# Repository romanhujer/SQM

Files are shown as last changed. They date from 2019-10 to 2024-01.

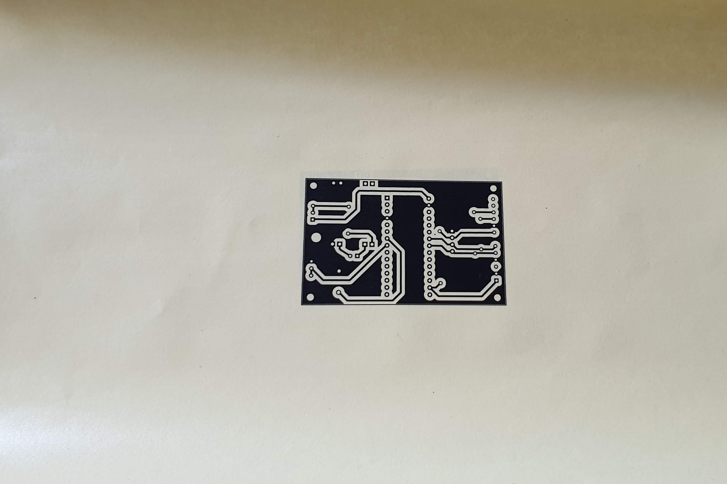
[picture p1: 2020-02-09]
Doc/PCB-Laser-print.jpg

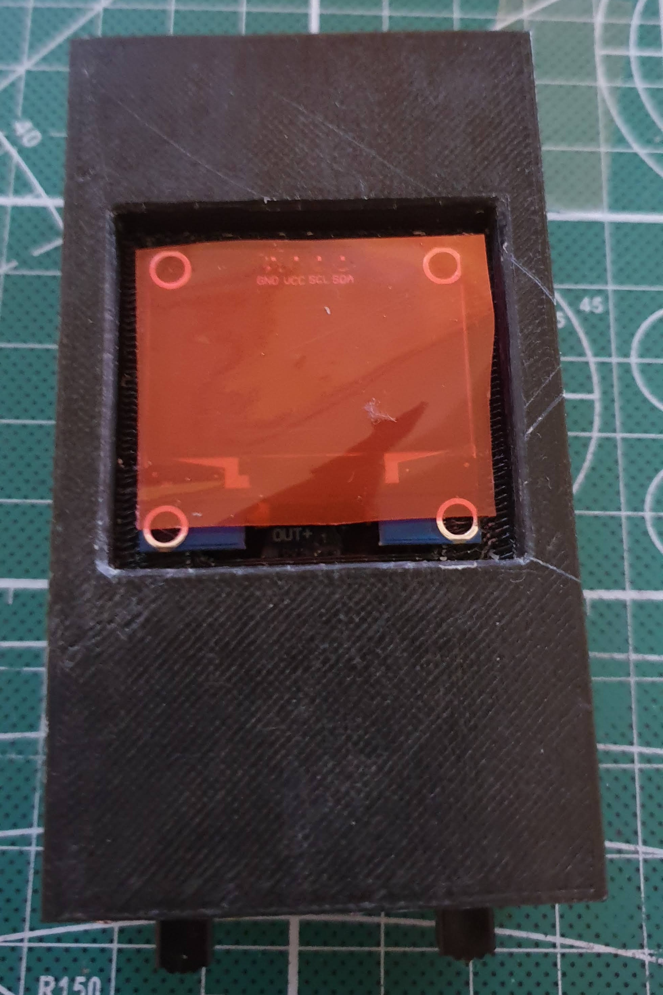
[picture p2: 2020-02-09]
Doc/install display.jpg

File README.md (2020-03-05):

# SQM
Arduino compatible Sky Quality Meter using the TSL2591
   
  base on https://github.com/gshau/SQM_TSL2591/
 
  and BME280 weather sensor 

## [Handheld version on base Adruino NANO](https://github.com/romanhujer/SQM/tree/master/SQM_nano)
  
  Used  128x64 OLED display 0.96" (SSD1306) or 1.3" (SH1106)
  and USB Control mode use derived Unihedron serial protokol

  * Wiring diagram a PCB  on [EasyEDA](https://easyeda.com/hujer.roman/sqm-hr)
  * Final 3Dmodel for case is on [Thingiverse](https://www.thingiverse.com/thing:4051029)

## [Fix instalaltion Vesion on base ESP8266 (ESP-01 or ESP-12)](https://github.com/romanhujer/SQM/tree/master/SQM_esp)

  Used wifi to send measurement data to server 
  * Wiring diagram a PCB for ESP-01 on  [EasyEDA](https://easyeda.com/hujer.roman/esp-01-sqm)
    * Basic simple version
  
  * Wiring diagram a PCB for ESP-12 on [EasyEDA](https://easyeda.com/hujer.roman/sqm-esp-v2) 
    * Possible battery operation and deepsleep  mode

## [Handheld Pro version on base ESP8266 (ESP-12)](https://github.com/romanhujer/SQM/tree/master/SQM_pro)

  Wiring diagram a PCB on [EasyEDA](https://easyeda.com/hujer.roman/sqm-esp-v2_copy) 
  
  * NOTE: The wiring diagram may change !
  
  Featuers plan:
   * 128x64 OLED display  1.3" (SH1106)
   * GPS  mudule (Optional)
   * For send measurement data to server used Wifi or Unihedron serial protokol

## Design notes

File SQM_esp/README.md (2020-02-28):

# ESP SQM
This is the EPS-01 and ESP8266 SQM 

# Installing the ESP8266 Platform
Before you can flash the firmware on your ESP8266 device, you need to install the ESP8266
platform for the Arduino IDE.

Under Preferences add this line in the additional "Boards Manager" area:
  http://arduino.esp8266.com/stable/package_esp8266com_index.json

Then from the "Tools, Boards, Boards Manager" menu select and install the ESP8266 add-on.

# Required libraries
* Adafruit Unified Sensor
* BMx280MI

# Flashing 
The exact flashing procedure depends on which ESP8826 device you will be using.

In the Arduino IDE, pick your device from "Tools, Boards". 

For an ESP-01, select "Generic 8266 Module".

Pin CHPD/EN must be HIGH (connected to 3.3V)
Pin GPIO0 must be LOW (connected to GND).  Use flash swich on PCB and reset

For the ESP-01, use the following parameters under Tools:

- Board: "Generic ESP8266 Module"
- Flash Mode: "DIO"
- Erase Flash: "Sketch + WiFi Settings"
- Flash Size: "1M (64K SPIFFS)" (Most ESP01 have 1M, older ones have 512K)
- Flash Frequency: "40MHz"
- CPU Frequency: "80 MHz"
- Reset Method: "ck"
- Upload Speed: "115200"
- Debug Port: "Disabled"
- Debug Level: "None"

Open the SQM_esp.ino file inside this folder. Check the "Config.h" file and set your vaules  for 
<pre>
 const char* sensor_key = "xxxxxxxxxxxxxxxxxx";  // For auth on web server
 const char* host = "my.cloud.iot";
 String app      = "/app.bin";  //URI for HTTP GET  app
 const char* ssid  = "my_ssid";
 const char* password = "my_password";
 
</pre>

# Wiring and PCB 
see
* https://easyeda.com/hujer.roman/esp-01-sqm
* https://easyeda.com/hujer.roman/sqm-esp-v2

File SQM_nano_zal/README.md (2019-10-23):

# SQM
Arduino compatible Sky Quality Meter using the TSL2591
   
  base in https://github.com/gshau/SQM_TSL2591/
 
  and BME280 weather sensor 
  
  and 128x64 OLED display 0.96" (SSD1306) or 1.3" (SH1106)

  Wiring diagram a PCB  on   https://easyeda.com/hujer.roman/sqm-hr

## Features

### USB Control mode use derived Unihedron serial protokol

#### Box info (Original Unihedron protokol)
* Request: ix 
* Response:  i,00000002,00000003,00000001,20191012

#### Read data  (Original Unihedron protokol)
* Request: rx  
* Response: r, 10.28m,0000000000Hz,0000000002c,000005.000s, 026.2C
or
* Request: ux  
* Response: u, 10.33m,0000000000Hz,0000000004c,000005.000s, 026.4C

#### Read extension data with weather informations (is my extension)
* Request: wx  
* Response: w, 11.87m,0.04e,00121i,00834v,0000000002c,A5,11,040h,0952p, 026.1C
 
#### Read config data  
* Request:  gx
* Response: g, 000.00m, 000.0C,TC:Y,A5,11,DC:0
 
#### Write SQM offset to EEPROM value range (-25m ... 25m)
Negative value: 
* Request:  zcal1-0.05x
* Response: z,1,-00.05m

Positive value:  
* Request:  zcal100.01x
* Response: z,1, 00.01m 

#### Write Temperature offset to EEPROM value range (-50°C ... 50°C)
Negative value: 
* Request:  zcal2-1.5x
* Response: z,2,-01.5C 

Positive value:  
* Request:  zcal2 00.5x
* Response: z,2, 00.5C 

#### Write default display contras to EEPROM value range (0-255) 
* Request:  zcal3 005x
* Response: z,3,005

#### Enabel SQM  temperature calibration 

* Request: zcalex
* Response: zxeaL 

#### Disable SQM  temperature calibration   (note lower case "d")

* Request:  zcaldx
* Response: zxdaL 

#### Erase EEPROM set to default value 

* Request: zcalDx
* Response: zxdL 

#### Oled display mode

* Request: A50x   Disable OLED display in USB mode
* Request: A51x   Enable OLED display in USB mode
* Request: A5dx   Disable auto dimmer (contras) for OLED display
* Request: A5ex   Enable auto dimmer (contras) for OLED display
* Request: A5x    Query for current OLED display mode

* Response: A5,xy 

  x... 0 - disable 1 - enable OLED Display in USB mode 
  
  y... 0 - disable 1 - enable auto Dimmer (contras) for OLED Display

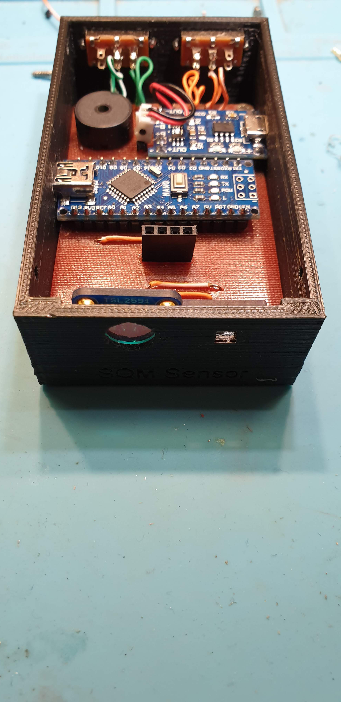
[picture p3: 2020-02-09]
Doc/in box1.jpg

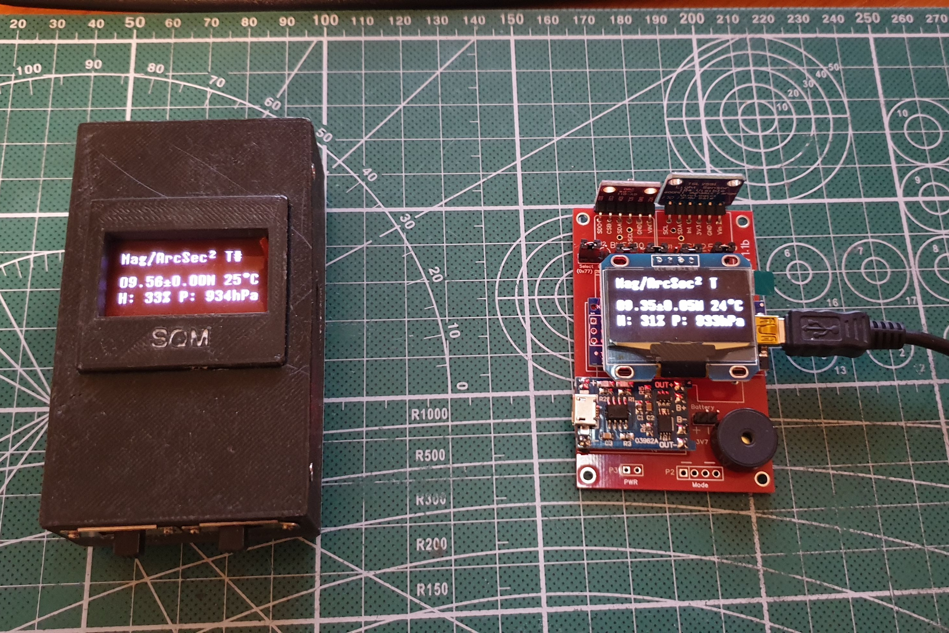
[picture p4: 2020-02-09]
Doc/Prototype II.jpg

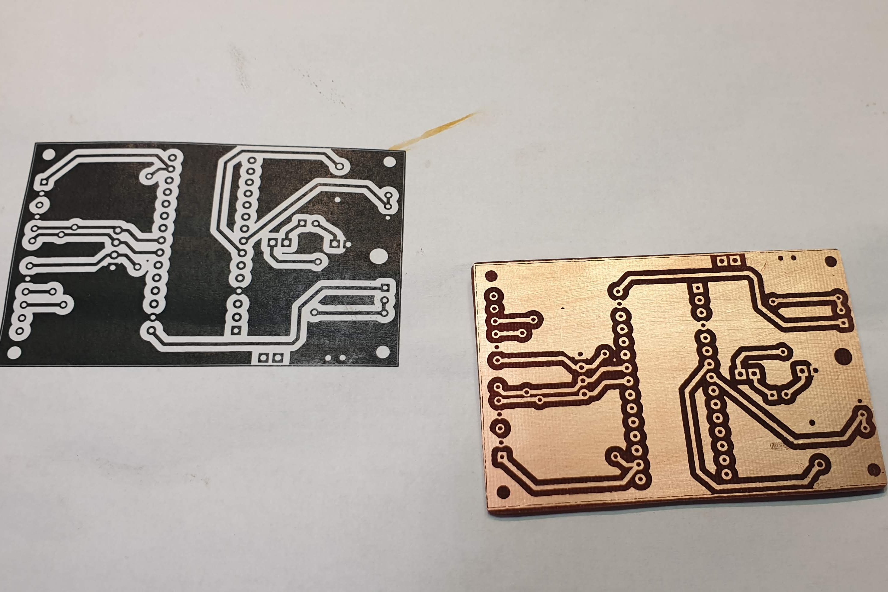
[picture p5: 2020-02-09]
Doc/HomeMadePCB-V1.0.jpg

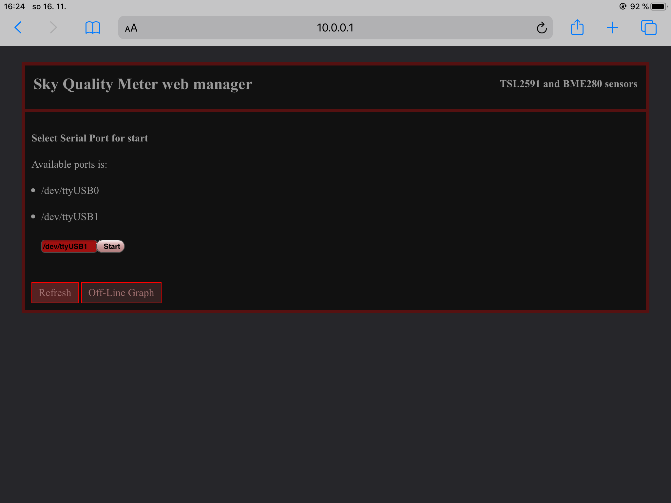
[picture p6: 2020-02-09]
Doc/WebManager Init.PNG

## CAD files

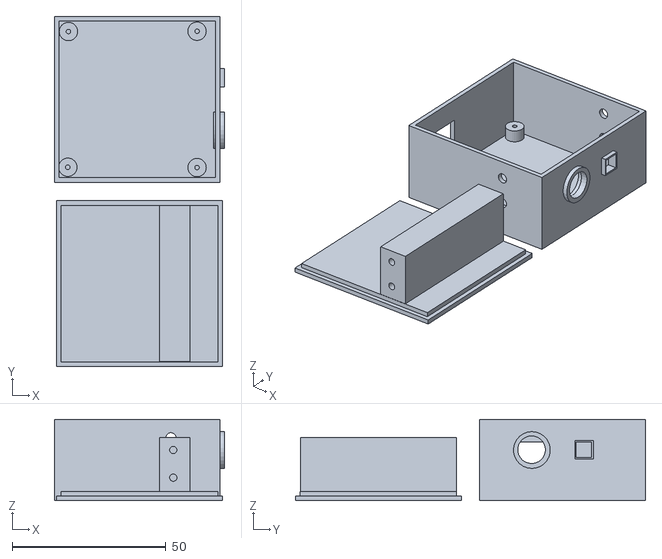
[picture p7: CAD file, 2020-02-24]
3DModelsForCase/stl_esp01/ESP-01-SQM1-main.stl
55.5 x 114.0 x 26.5

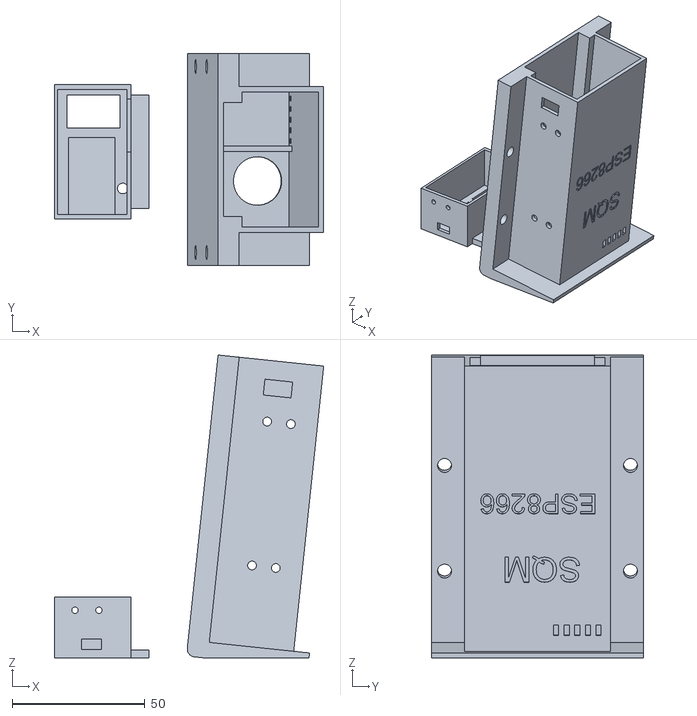
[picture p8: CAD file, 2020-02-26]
3DModelsForCase/stl_esp8266/SQM-ESP8266-cover-main.stl
101.5 x 80.0 x 114.1

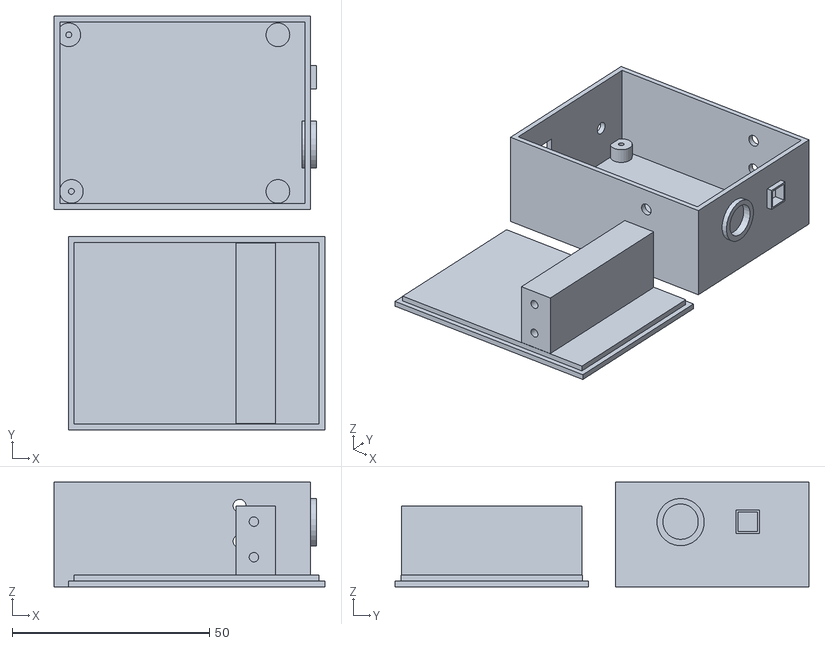
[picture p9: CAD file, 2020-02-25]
3DModelsForCase/stl_esp8266/SQM-ESP8266-box_main.stl
68.6 x 104.8 x 26.5

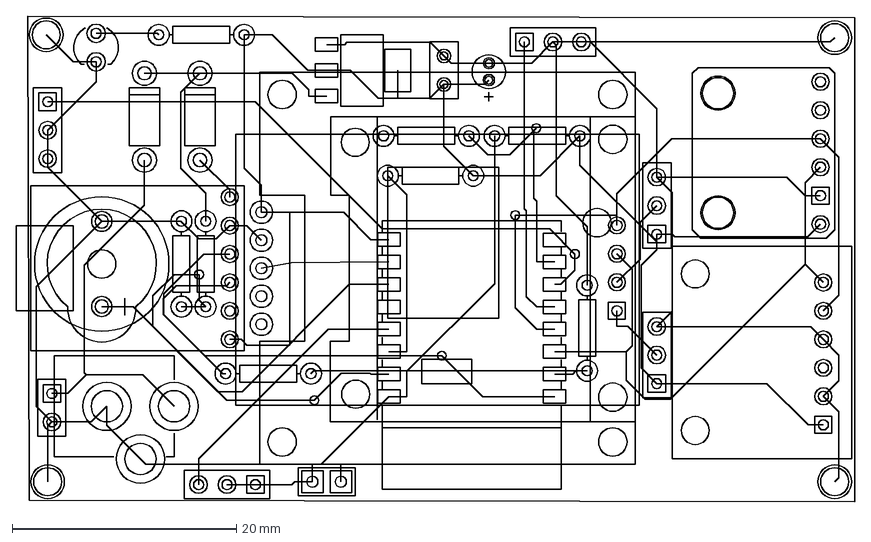
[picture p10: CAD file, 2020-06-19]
3DModelsForCase/SQM ESP pro V2.5_2020-06-01_20-28-58.dxf
74.8 x 43.3 mm

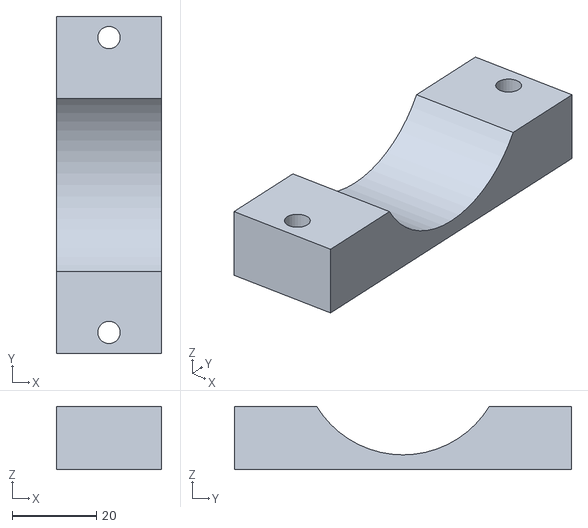
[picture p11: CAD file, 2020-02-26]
3DModelsForCase/stl_esp01/SQM-ESP-holder.stl
25.0 x 80.0 x 15.0

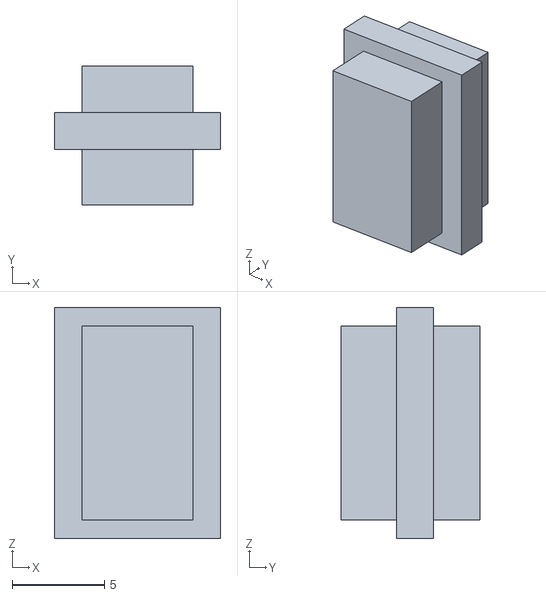
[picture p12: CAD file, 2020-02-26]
3DModelsForCase/stl_esp8266/SQM-ESP8266-usb_fixed.obj
9.00 x 7.50 x 12.5

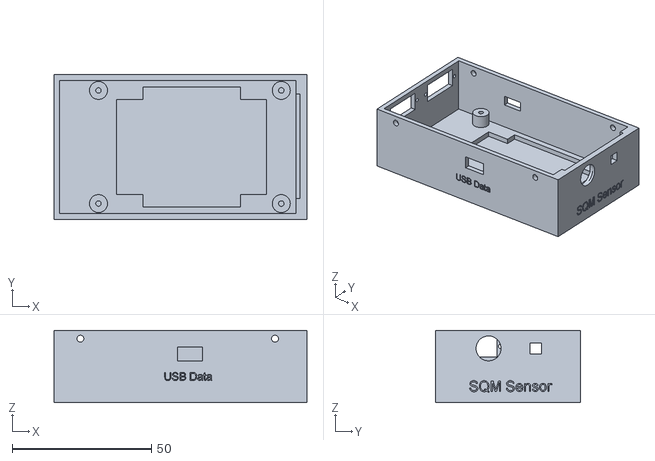
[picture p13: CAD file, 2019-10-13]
3DModelsForCase/stl_nano/SQMBoxB_fixed.stl
91.0 x 52.0 x 26.0

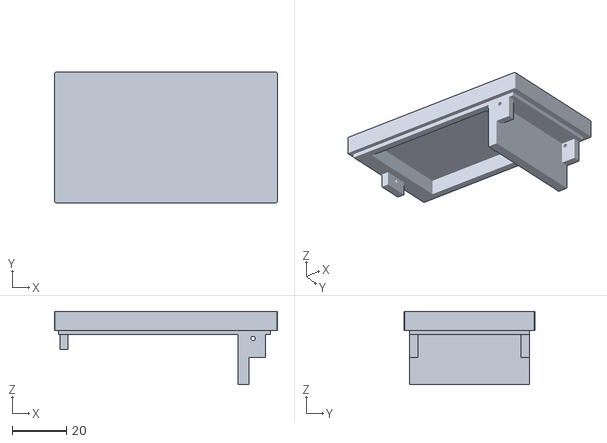
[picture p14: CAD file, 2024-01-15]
3DModelsForCase/stl_pro/SQM_BOX-Fillet002.stl
82.0 x 48.0 x 27.0

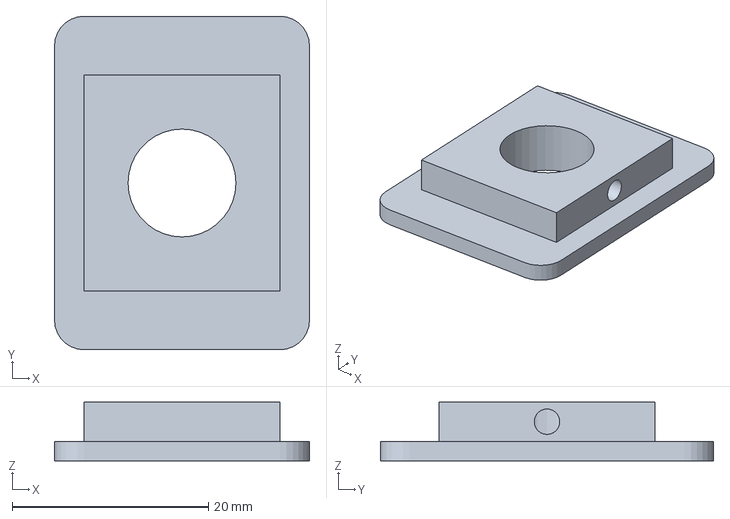
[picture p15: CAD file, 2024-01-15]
SQM_pro/master.3mf
26.0 x 34.0 x 6.00 mm

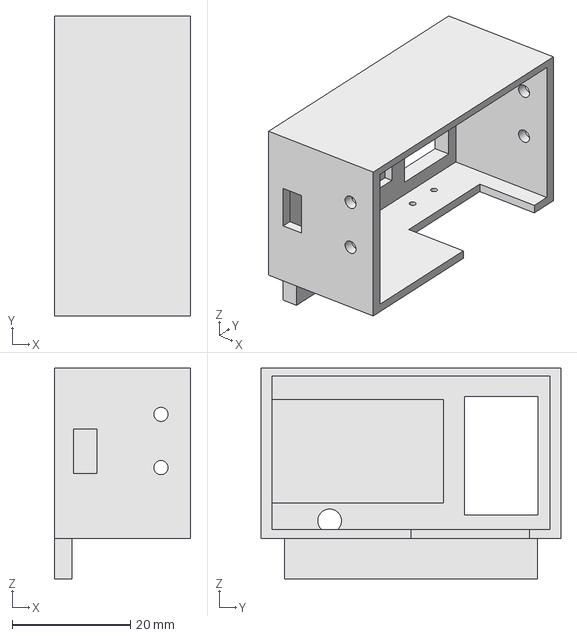
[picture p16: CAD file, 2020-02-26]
3DModelsForCase/SQM_BOX.FCStd
23.0 x 50.7 x 35.6 mm

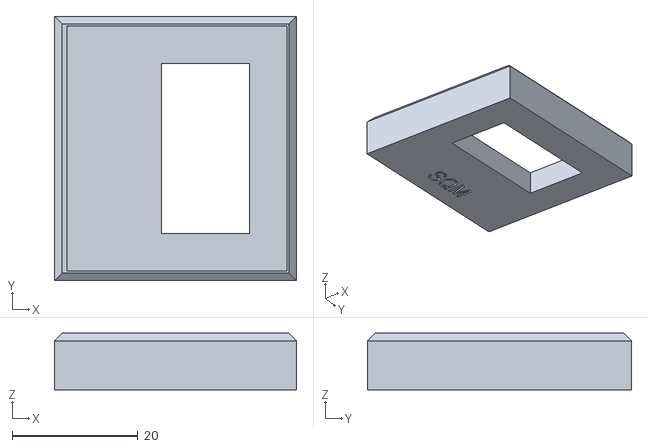
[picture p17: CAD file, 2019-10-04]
3DModelsForCase/stl_nano/SQMFaceSSD1306_fixed.stl
38.5 x 42.0 x 9.00

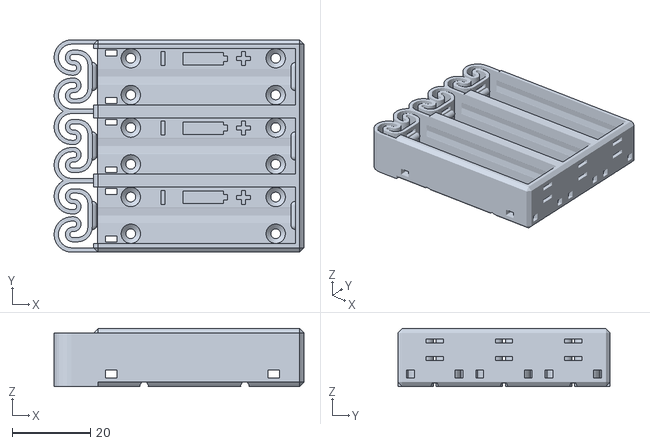
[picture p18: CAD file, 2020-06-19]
3DModelsForCase/stl_pro/flexbatterAAx3.stl
64.0 x 54.4 x 14.9

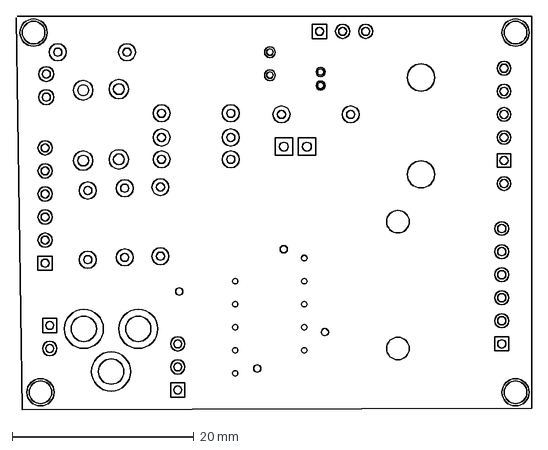
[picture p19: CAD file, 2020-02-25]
3DModelsForCase/SQM ESP v2.dxf
56.8 x 43.3 mm

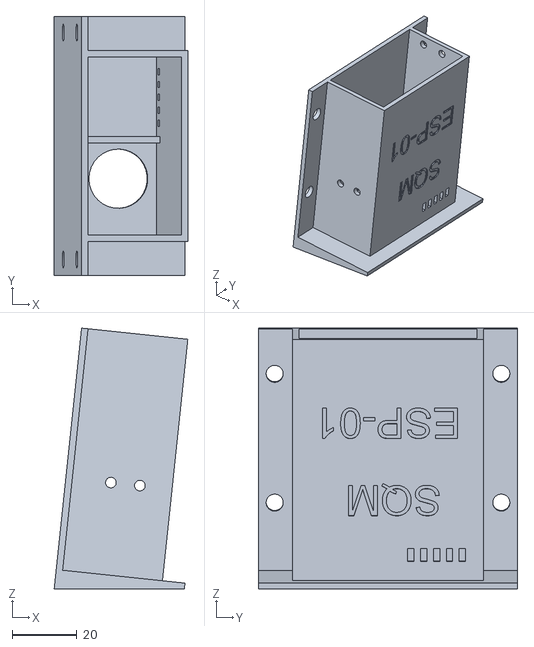
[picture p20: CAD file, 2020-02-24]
3DModelsForCase/stl_esp01/ESP-01-SQM-cover.stl
41.3 x 80.0 x 80.6

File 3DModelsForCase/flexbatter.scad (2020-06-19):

//////////////////////////////////////////////////////////////////////////////////////
///
///  FLEXBATTER: Flexing battery holder with built-in spring
///
///  This file generates battery holders for arbitrary cylindrical sizes.
///  The number of batteries and their size is fully parametrized.
///
///  The usual metallic spring at the minus pole is replaced by a
///  flexible printed spring, which is pressing the contacts firmly to 
///  the battery.
///
///  The contacts for the plus and minus pole can easily be made by
///  a few windings of the uninsulated ends of the connecting wires.
///  Each battery compartment contains are several holes to the outside
///  as well ad to the neighboring compartments, through which connecting
///  wires can be passed for easy configuring of parallel, serial or
///  balanced-serial battery packs.
///  
///  The preconfigured battery sizes are:
///  AA, AAA, C, D, 18650(Li-Ion), 18650P(protected Li-Ion), CR123A(16340)
///  
///  Given that the printed plastic spring needs to be flexible, ABS is the material
///  of choice here.
///
//////////////////////////////////////////////////////////////////////////////////////
///
///  2014-09-09 Heinz Spiess, Switzerland
///
///  released under Creative Commons - Attribution - Share Alike licence (CC BY-SA)
//////////////////////////////////////////////////////////////////////////////////////

flexbatterAAA(n=2);

// build a cube with chamfered edges
module chamfered_cube(size,d=1){
   hull(){
     translate([d,d,0])cube(size-2*[d,d,0]);
     translate([0,d,d])cube(size-2*[0,d,d]);
     translate([d,0,d])cube(size-2*[d,0,d]);
   }
}


// draw an arc width height h between radius r1..r2 and angles a1..a2
module arc(r1,r2,h,a1=0,a2=0){
     if(a2-a1<=180){
        difference(){
           cylinder(r=r2,h=h);
           translate([0,0,-1])cylinder(r=r1,h=h+2);
	   rotate(a2)translate([-r1-r2,0,-1])cube([2*(r1+r2),2*(r1+r2),h+2]);
	   rotate(a1+180)translate([-r1-r2,0,-1])cube([2*(r1+r2),2*(r1+r2),h+2]);
        }
     } else {
           difference(){
              cylinder(r=r2,h=h);
              translate([0,0,-1])cylinder(r=r1,h=h+2);
              intersection(){
	       rotate(a2)translate([-r1-r2,0,-1])cube([2*(r1+r2),2*(r1+r2),h+2]);
	       rotate(a1+180)translate([-r1-r2,0,-1])cube([2*(r1+r2),2*(r1+r2),h+2]);
	      }
           }
     }
}

/////////////////////////////////////////////////////////////////////////////////
// sline - generate a "snake line" of width w and height h 
// with a arbitrary sequence of segments defined by a radius and a turning angle
//
//   angle[i] > 0  left turn / counter-clockwise
//   angle[i] < 0  left turn / clockwise
//   angle[i] = 0  straight segment with length radius[i]
//
/////////////////////////////////////////////////////////////////////////////////
// Heinz Spiess, 2014-09-06 (CC BY-SA)
/////////////////////////////////////////////////////////////////////////////////
module sline(angle,radius,i,w,h){
   scale([angle[i]>=0?1:-1,1,1])
      assign(r=abs(radius[i]))assign(a=angle[i])
         translate([a?r:0,0,0]){
	    translate([-w/2,-r-0.01,0])cube([w,0.02,h]); // tiny overlap!
            if(a)arc(r-w/2,r+w/2,0,a,h=h);
	    else if(r>0)translate([-w/2,-r,0])cube([w,r,h]);
      if(i+1<len(angle))
           rotate(angle[i])
	      translate([a?-r:0,a?0:-r,0])
	         sline(angle,radius,i+1,w,h);
  }
}

//////////////////////////////////////////////////////////////////////////////////
//
//  FLEXBATTER:  Flexing battery holder with integrated plastic spring
//
//////////////////////////////////////////////////////////////////////////////////
module flexbatter(n=1,l=65,d=18,hf=0.75,r=4,shd=3,eps=0.28,el=0,xchan=[1/4,3/4],$fn=24){
ew=0.56;   // extrusion width
eh=0.25;   // extrusion height
w = 4*ew;  // case wall thickness
ws = 2*ew; // spring wall thickness
ch = w-ws; // edge chamfering
deepen=0; //deepening for side grip of batteries
//el = 0;  // extra length in spring
//eps = 0.28;
//shd = 3; // screw hole diameter
//hf=0.75;
//xchan=[1/4,3/4]; // relative position of traversal wire channels

r = d/5+2*ws; // linear spring length (depends on sline() call!)

   for(i=[0:n-1])translate([0,i*(d+w+ws),0]){ // generate n battery cases
      difference(){
         
         union(){
            difference(){
               // main body
               translate([0,-w-d/2,0])
	          chamfered_cube([l+w,d+2*w+(i<n-1?ws:0),hf*d+w+ch],ch);
	       // main cavity
               translate([-2,-d/2,w])cube([2+l,d,d+1]);
	       // cavity for locating plastic spring
               translate([-1,-d/2,-1])cube([2,d,d+w+2]);
	       // small cylindrical carving of walls and bottom
	       if(eps>0)translate([-1,0,d/2+w])rotate([0,90,0])cylinder(r=d/2+eps,h=l+1);
            }
      
            // plastic spring for minus pole
            for(sy=[-1,1])scale([1,sy,1])assign(D=d+2*w-2*ws-0.7){
               translate([ch,d/2+w-ws/2,0])rotate(-90)
		  //sline([90,0,120,90,120,90,0],[d/8+2,d/6,d/8-1,d/8,-d/8,d/8,d/2],0,ws,hf*d+w);
		  sline([0,180,0,180,0,-180,0,90,0],[r+ch+el,D/4,el,D/12,el/2,D/12,1+el/2,D/5,D/3],0,ws,hf*d+w);


            }
         }
      
         // lower and upper holes for contacts
         for(z=[-2*ws,2*ws])
            translate([-2*ws,-w,w-ws/2+d/2+z])cube([l+2*w+2,2*w,ws]);
      
         // longitudinal bottom wire channel
         translate([-2*ws,0,0])rotate([0,90,0])cylinder(r=w/2,h=l+w+2+r,$fn=5);
      
         // traversal bottom wire channels
         for(x=l*xchan)translate([x,-d/2-w-1,eh]) rotate([-90,0,0])cylinder(r=w/2,h=d+2*w+ws+2,$fn=6);
   
         // grip deepening
	 if(deepen>0)
            translate([w+l/2-0.5,-d/2-w-0.01,w+d+l])
	       rotate([-90,0,0]){
	          cylinder(r=l+deepen*d,h=d+2*w+2*ws+2,$fn=72);
	          if(i==0)cylinder(r1=l+deepen*d+ch,r2=l+deepen*d,h=ch+0.02,$fn=72);
	          if(i==n-1)translate([0,0,d+2*w-ch])cylinder(r2=l+deepen*d+ch,r1=l+deepen*d,h=ch+0.02,$fn=72);

               }
         // conical screw holes in corners
         for(x=[7+shd,l-2*shd])for(y=[-d/2+shd,d/2-shd])
             translate([x,y,-1]){
                cylinder(r=shd/2,h=w+2);
                translate([0,0,w-shd/2+1])cylinder(r1=shd/2,r2=shd,h=shd/2+0.01);
             }

         // holes for wires passing inside
         for(sy=[-1,1])scale([1,sy,1]){
	    translate([l-1,-d/2,w])cube([w+2,2,2]);
            for(x=[3,l-7])translate([x,-d/2-w-ws-1,w])cube([3,w+ws+3,2]); 
            translate([3,-d/2+w/2-0.75,-1])cube([3,1.5,w+2]); 
            translate([-0.5,-d/2+w/2,0])rotate([0,90,0])cylinder(r=w/2,h=6.5,$fn=5);
         }

         // engrave battery symbol
	 translate([w+l/2,d/4+1,w])cube([l/5,d/4.5,4*eh],true);
	 translate([w+l/2+l/10,d/4+1,w])cube([d/7,d/10,4*eh],true);
	 // engrave plus symbol
	 assign(sy=(l>12*shd)?1:-1){ // for short batteries +- on the side
	    translate([w+l/2+l/(sy>0?5:10),sy*(d/4+1),w]){
	       cube([1,d/4,4*eh],true);
	       cube([d/4,1,4*eh],true);
            }
	 // engrave minus symbol
	    translate([w+l/2-l/(sy>0?5:10),sy*(d/4+1),w])
	       cube([1,d/4,4*eh],true);
         }
   
         //correction for middle separators
         //if(i<n-1) translate([-d,d/2+w-ws/2,-1])cube([d,ws/2+0.1,d+2]);
	 //else translate([1,d/2+w,-0.01])cylinder(r1=ch,r2=0,h=ch);
         //if(i>0) translate([-d,-d/2-w-0.1,-1])cube([d,ws/2+0.1,d+2]);
	 //else translate([1,-d/2-w,-0.01])cylinder(r1=ch,r2=0,h=ch);


      }


      // horizontal contact bulges (+ and - pole)
      for(x=[-0.3,l])
         hull()for(y=[-3+el,3-el])
            translate([x,y,w+d/2])sphere(r=ws);
   
      // vertical contact bulge (+ pole only)
      if(0)hull()for(z=[-3+el,3-el])for(x=[0,w-ws])
            translate([l+x,0,w+d/2+z])sphere(r=ws);



   }

}

module flexbatter18650(n=1){
   flexbatter(n=n,l=65.5,d=18.4,hf=0.75,shd=3,eps=0.28);
}  

module flexbatter18650P(n=1){
   flexbatter(n=n,l=67.5,d=18.4,hf=0.75,shd=3,eps=0.28);
}  

module flexbatterCR123A(n=1){
   flexbatter(n=n,l=35.1,d=16.7,hf=0.75,shd=3,xchan=[0.5],eps=0.28);
}  

module flexbatterD(n=1){
   flexbatter(n=n,l=61.5,d=34.0,hf=0.75,shd=3,eps=0.28);
}  

module flexbatterC(n=1){
   flexbatter(n=n,l=51.6,d=26.4,hf=0.75,shd=3,eps=0.28);
}  

module flexbatterAA(n=1){
   flexbatter(n=n,l=51.6,d=14.4,hf=0.80,shd=2.5,el=0.5,eps=0.28);
}  

module flexbatterAAA(n=1){
   flexbatter(n=n,l=46.1,d=10.45,hf=0.84,shd=2,el=1,xchan=[0.5],eps=0);
}  

module flexbatter18650x1(){ // AUTO_MAKE_STL
  flexbatter18650(n=1);
}

module flexbatter18650Px1(){ // AUTO_MAKE_STL
  flexbatter18650P(n=1);
}

module flexbatterCR123Ax1(){ // AUTO_MAKE_STL
  flexbatterCR123A(n=1);
}

module flexbatterAAx1(){ // AUTO_MAKE_STL
  flexbatterAA(n=1);
}

module flexbatterAAAx1(){ // AUTO_MAKE_STL
  flexbatterAAA(n=1);
}

module flexbatterCx1(){ // AUTO_MAKE_STL
  flexbatterC(n=1);
}

module flexbatter18650x2(){ // AUTO_MAKE_STL
  flexbatter18650(n=2);
}

module flexbatterAAx2(){ // AUTO_MAKE_STL
  flexbatterAA(n=2);
}
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

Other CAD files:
3DModelsForCase/stl_esp01/SQM-ESP-holder_fixed.obj
3DModelsForCase/stl_esp8266/SQM-ESP-holder_fixed.obj
3DModelsForCase/stl_nano/SQMBoxT_fixed.stl
3DModelsForCase/ESP-01 SQM.dxf
3DModelsForCase/SQM PCB V1.0.dxf
3DModelsForCase/stl_esp01/ESP-01-SQM-box_fixed.obj
3DModelsForCase/stl_esp01/ESP-01-SQM-cap_fixed.obj
3DModelsForCase/stl_esp01/ESP-01-SQM-cover_fixed.obj
3DModelsForCase/stl_esp8266/SQM-ESP8266-box_fixed.obj
3DModelsForCase/stl_esp8266/SQM-ESP8266-cap_fixed.obj
3DModelsForCase/stl_esp8266/SQM-ESP8266-cover.stl
3DModelsForCase/stl_esp8266/SQM-ESP8266-cover_fixed.obj
3DModelsForCase/stl_esp8266/SQM-ESP8266-power.stl
3DModelsForCase/stl_esp8266/SQM-ESP8266-power_fixed.obj
3DModelsForCase/stl_esp8266/SQM-ESP8266-usb.stl
3DModelsForCase/stl_nano/SQMBoxB_fixed.obj
3DModelsForCase/stl_nano/SQMBoxT_fixed.obj
3DModelsForCase/stl_nano/SQMFace SH1106_fixed.obj
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

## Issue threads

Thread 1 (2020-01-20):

SQM values

porkyhttp, 2020-01-20:
SQM values, has been compared with values of an official SQM device???

romanhujer, 2020-01-20:
Yes, I compared  my prototypes with the origilnal Unihedron SQM.
After setting the default "SQM offset" the measurements show a +-0.1MAS  error
(SQM temperature calibration is need to turn off does not work properly)

porkyhttp, 2020-01-20:
Which version of the BMx280I2C.h did you used?

romanhujer, 2020-01-21:
The resulting machine code is smaller when using BMx280I2C.h than with BME280I2C.h in ATMega328p, there is no more space. Extended functions that are in BMx280I2C.h do not need here.

Roman

porkyhttp, 2020-01-21:
This code with libs are to big to fit in an Arduino Nano or Uno. Is possible to have a version without the display support? I only need serial connection via USB and or via INDI

Closed 2020-01-20.

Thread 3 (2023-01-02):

Display does not changed from "Wait first data"

otherwild, 2023-01-02:
Hello. I made a PCB based on EasyEDA information and installed the components. Then, I installed the program source at the following URL on Arduino nano with ArduinoIDE.

”https://github.com/romanhujer/SQM/tree/master/SQM_nano”

After that, when the power was turned on, the initialization information and "Wait first data" were displayed on the OLED screen, but the display did not change from "Wait first data".
I would like to investigate the issue and would appreciate your assistance.

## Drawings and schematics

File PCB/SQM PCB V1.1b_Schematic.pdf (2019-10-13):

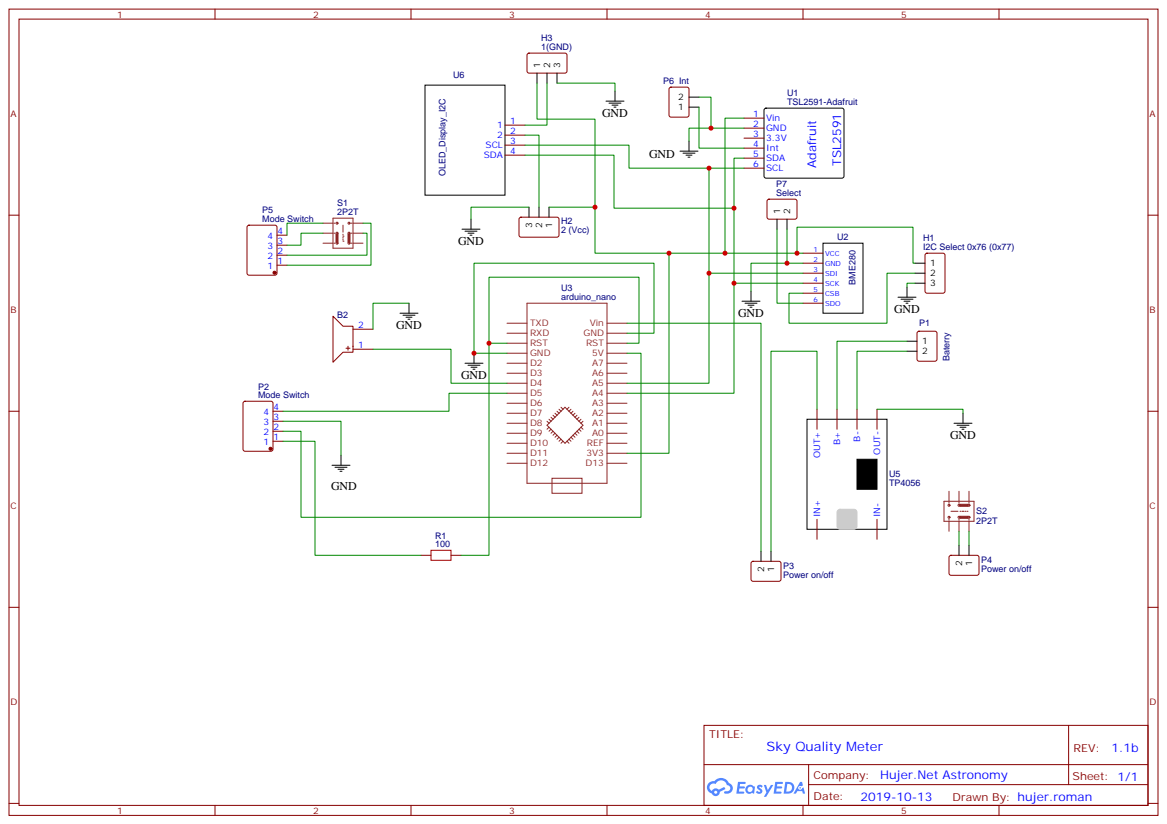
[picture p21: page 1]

Company: Hujer.Net Astronomy

Drawn By: hujer.roman

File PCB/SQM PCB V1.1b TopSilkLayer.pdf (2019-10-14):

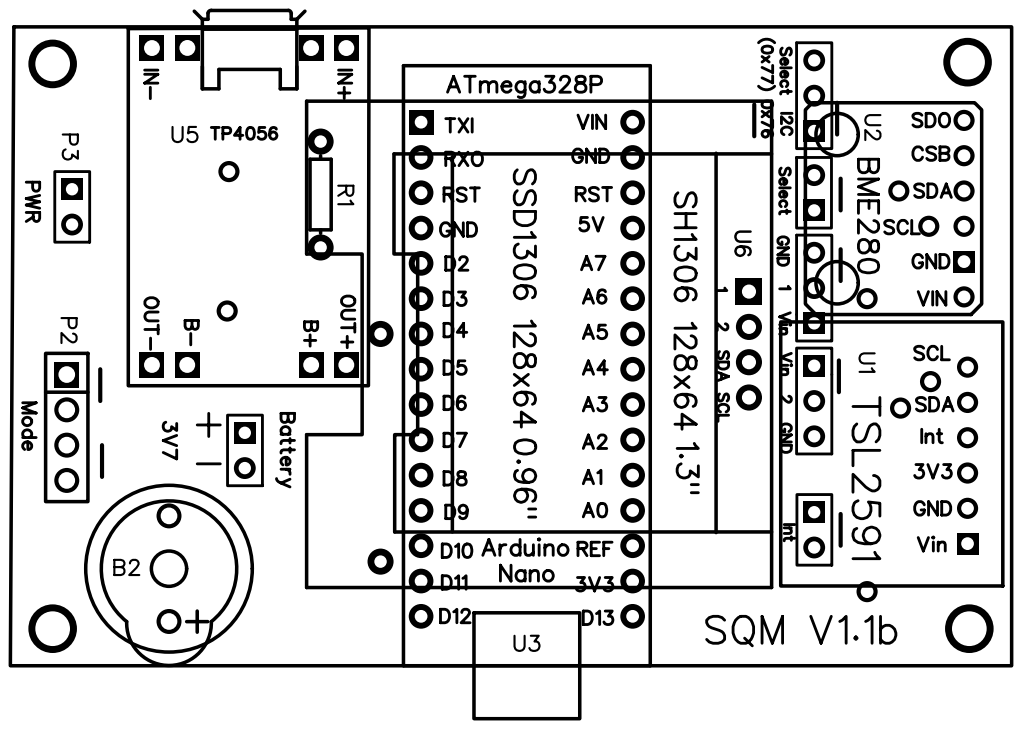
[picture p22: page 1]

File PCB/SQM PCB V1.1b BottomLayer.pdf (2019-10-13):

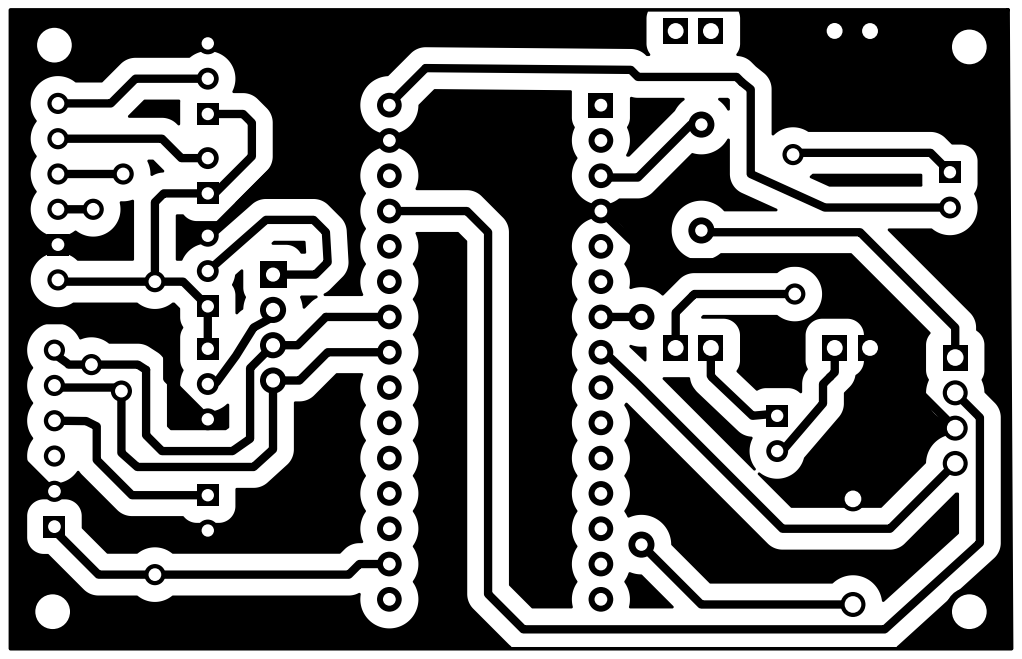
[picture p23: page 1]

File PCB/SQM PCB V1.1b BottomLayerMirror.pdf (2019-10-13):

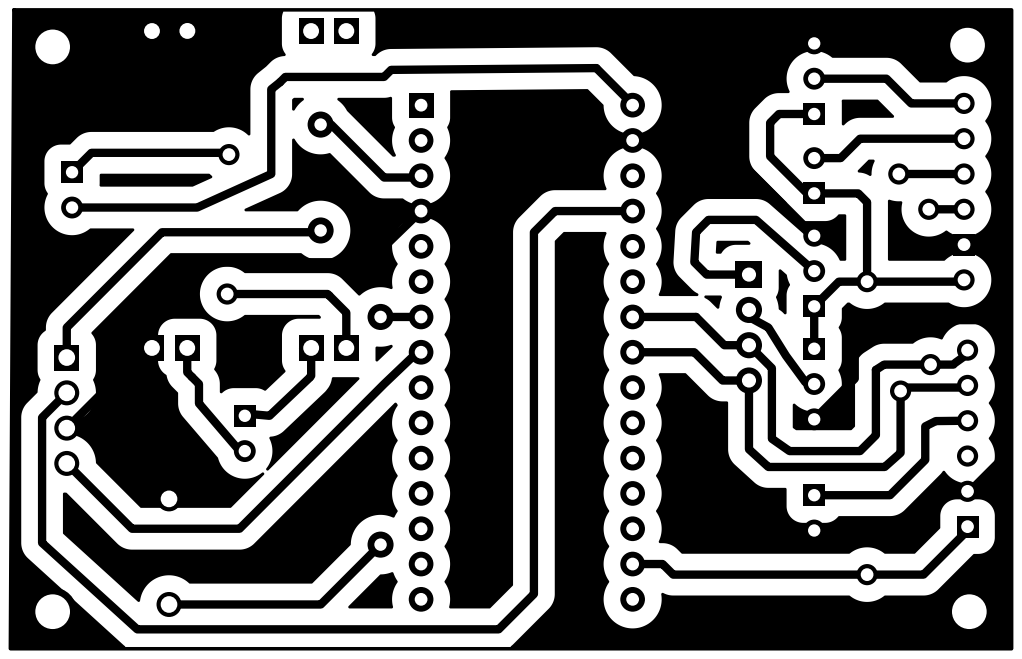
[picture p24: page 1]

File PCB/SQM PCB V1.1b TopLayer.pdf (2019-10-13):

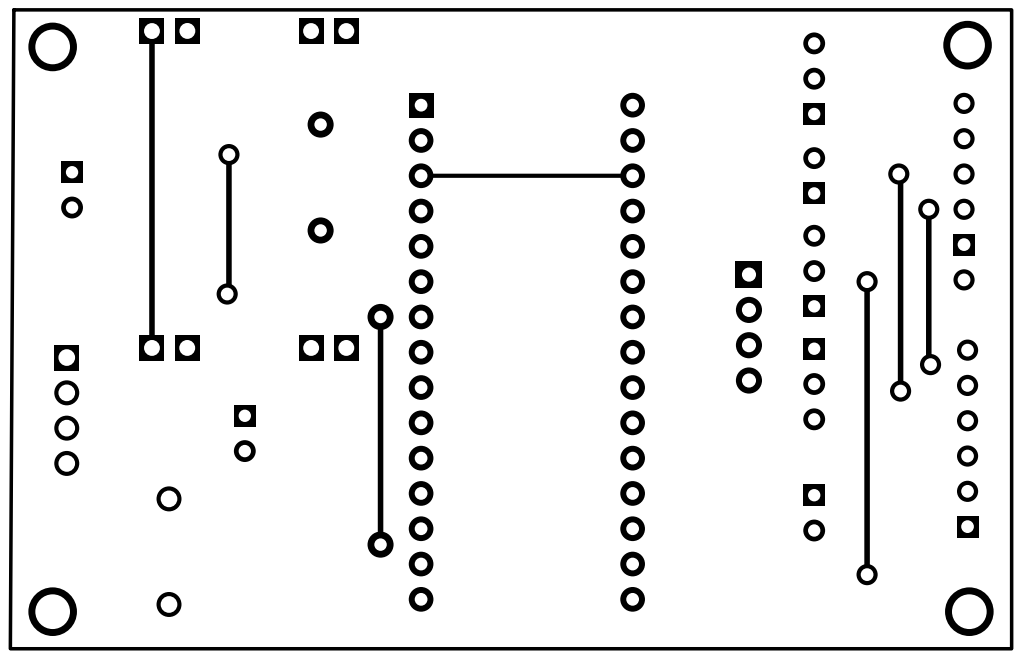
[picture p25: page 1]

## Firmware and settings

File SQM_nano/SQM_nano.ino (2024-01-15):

/*
   SQM.ino   Sky Quality Meter

   Copyright (c) 2019 Roman Hujer   http://hujer.net

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
  Description:
  Sky Quality Meter using the TSL2591

  base on https://github.com/gshau/SQM_TSL2591/

  and BME280 weather sensor

  and 128x64 OLED I2C display 0.96" (SSD1306) or 1.3" (SH1106)

  Wiring diagram a PCB  on   https://easyeda.com/hujer.roman/sqm-hr

*/
#define Version "1.0.9"
#define SERIAL_NUMBER "20200210"
#include "Config.h"
#include "Setup.h"
#include "Validate.h"

#include <Wire.h>
#include <EEPROM.h>
#include <BMx280I2C.h>
#include <U8x8lib.h>


#include <Adafruit_Sensor.h>
#include <Adafruit_TSL2591.h>
#include <Adafruit_GFX.h>
#include <math.h>

#define LOWSCALE 1.0
#define MEDSCALE 25.0
#define HIGHSCALE 428.0
#define MAXSCALE 9876.0

// Setup  OLed Display

#ifdef SH1106_ON
      U8X8_SH1106_128X64_NONAME_HW_I2C OledDisp(/* reset=*/ U8X8_PIN_NONE);
#endif  
#ifdef SSD1306_ON
       U8X8_SSD1306_128X64_NONAME_HW_I2C OledDisp(/* reset=*/ U8X8_PIN_NONE);
#endif 

// Setup temperatue sensor
BMx280I2C bme(BME_I2C_ADDRESS);

Adafruit_TSL2591 tsl=Adafruit_TSL2591(2591);
double gainscale = MAXSCALE;
uint32_t luminosity;
uint16_t ir, full, visible;
double adjustedVisible, adjustedIR;
double mag;

float SqmCalOffset =  SQM_CAL_OFFSET ;   // SQM Calibration offset from EEPROM
float TempCalOffset = TEMP_CAL_OFFSET;   // Temperature Calibration offset from EEPROM

boolean InitError = false;
boolean USBmodeON = false;
boolean SerialOK  = false;
boolean Blik      = false;
boolean Humidity  = true;

float temp = 0;
float hum = 0;
float pres = 0;
uint16_t counter = 0;
byte page = 0;
String BME_Msg;
String TSL_Msg;
char oled[6] = "A5,11";

void setup() {

  Wire.begin(); 
  pinMode(ModePin, INPUT_PULLUP);
  pinMode(BuzzerPin, OUTPUT);
  Serial.begin(SERIAL_BAUD);
  Serial.setTimeout(1000);
  Serial.println("Ready");
  if ( bme.begin()){ 
     if (bme.isBME280()){
        Humidity = true;
        BME_Msg  = "BME280  OK";
        bme.resetToDefaults();        
        bme.writeOversamplingPressure(BMx280MI::OSRS_P_x16);
        bme.writeOversamplingTemperature(BMx280MI::OSRS_T_x16);
        bme.writeOversamplingHumidity(BMx280MI::OSRS_H_x16);
     } else {
        Humidity = false;
        BME_Msg =  "no Humidity";                            
     }
  } else {

       BME_Msg =  "BME Err";
       InitError = true;
  }


  tsl.begin();
  tsl.setGain(TSL2591_GAIN_MAX);
  tsl.setTiming(TSL2591_INTEGRATIONTIME_600MS);

 
// Init Oled Dislay
if ( OledDisp.begin()) {
    OledDisp.setFont(OLED_FONT);
    OledDisp.setPowerSave(false);
    oled[3]='1';
    oled[4]= (ReadEEAutoContras())? '1' : '0';
    DisplFirstPage();
  }
  else {
    InitError = true;
    Serial.println("OLED Err");
  } // end of if (sqm.begin())

  if (InitError) {
     for (byte _i = 0; _i < 20; _i++) {
        buzzer(50);
        delay(50);
     }
     while (true);
   } // end of if (InitError) 
   
   delay(750); // Pause for 1 seconds

   SqmCalOffset = ReadEESqmCalOffset();     // SQM Calibration offset from EEPROM
   TempCalOffset = ReadEETempCalOffset();   // Temperature Calibration offset from EEPROM
   
//   sqm.setCalibrationOffset(SqmCalOffset);  // call offset
#ifdef EXTENDET_INFO_ON   
   DisplCalData();      
   delay(1500); // Pause for 1 seconds
#endif    
   DisplWait('#');
} // end of Setup

//=======================================================================================

void loop() {
  String response;
  
  if (digitalRead(ModePin))   {
    SerialOK  = false;
    if (USBmodeON) {
      buzzer(200);
    }
    USBmodeON = false;
  }
  else {

    if (!USBmodeON) {
      buzzer(200);
    }
    USBmodeON = true;
  }
  if ( !USBmodeON ) {
    OledDisp.setPowerSave(false);
    oled[3]='1';
    ReadWeather() ;

//    if (ReadEEAutoTempCal()) sqm.setTemperature( temp );  //temp call
    
    mySQM();  
    
    DisplSqm( mag,0, int(temp+0.5), int(hum), int(pres / 100), '#'); 

    delay(2000);
    
  }
    else {
//
// USB mode 
// ======================================================
    if (!SerialOK) {
      DisplWait('@');
      delay(50);
    }
     while ( Serial.available()) {       
      char  _sign;
      SerialOK  = true;
      
      
      if (digitalRead(ModePin))  break ;  // check end USB mode

      ReadWeather();
//      if (ReadEEAutoTempCal()) sqm.setTemperature( temp );   // SQM temp calib

      String counter_string = String(counter++);
      while ( counter_string.length() < 10) {
        counter_string = '0' + counter_string;
      }
   
      mySQM();
      String sqm_string = String( ( mag <0) ? -mag : mag, 2);
      while ( sqm_string.length() < 5) {
        sqm_string = '0' + sqm_string;
      }
      _sign = ( mag < 0 ) ? '-' : ' ';
      sqm_string = _sign + sqm_string;


      String temp_string = String( (temp < 0 ) ? - temp : temp, 1);
      while ( temp_string.length() < 5) {
        temp_string = '0' + temp_string;
      }
      _sign = ( temp < 0 ) ? '-' : ' ';
      temp_string = _sign + temp_string;
   
      String command = Serial.readStringUntil('x');

// Unit information request (note lower case "i")
      if ( command.equals("i")) {  
        Serial.print("i,00000002,00000003,00000001,");
        Serial.println(SERIAL_NUMBER);
        
// Reading request
      } else if ( command.equals("r")) { 

         Serial.println("r," + sqm_string 
                        + "m,0000000000Hz," 
                        + counter_string 
                        + "c,0000000.000s," 
                        + temp_string +'C');
//#ifndef SSD1306_ON
// Unaveraged reading request
      } else if (command.equals("u")) { 
         Serial.println("u," + sqm_string 
                        + "m,0000000000Hz,"                         
                        + counter_string 
                        + "c,0000000.000s," 
                        + temp_string +'C');

//#endif
#ifdef EXTENDET_PROTOCOL_ON

// My extension request for weather information
      } else if (command.equals("w")) { 
        // String ir_string = String(sqm.ir);
        while ( ir_string.length() < 5) { 
        ir_string = '0' + ir_string;
        }
       // String vis_string = String(sqm.vis);
        while ( vis_string.length() < 5) { 
          vis_string = '0' + vis_string;
        }
/*        String f_string = String(sqm.full);
        while ( f_string.length() < 5) { 
          f_string = '0' + f_string;
        }
*/        
        String hum_string = String(int(hum));
        while ( hum_string.length() < 3) { 
          hum_string = '0' + hum_string;
        }
        String pres_string = String(int(pres / 100));
        while ( pres_string.length() < 4) { 
         pres_string = '0' + pres_string;
       }
       Serial.println("w," + sqm_string + "m,"
                          + String(mag, 2) + "e,"
//                          + f_string + "f,"
//                          + ir_string + "i,"
//                          + vis_string + "v,"
                          + counter_string +"c,"
                          + oled + ',' 
                          + hum_string + "h,"
                          + pres_string + "p,"
                          + temp_string + 'C');
        
#endif // end of  EXTENDET_PROTOCOL_ON

// read Config information request
       } else if (command.equals("g")) { 
              sqm_string = String( (SqmCalOffset < 0 ) ? - SqmCalOffset : SqmCalOffset, 2);            
              while ( sqm_string.length() < 6) {
                 sqm_string = '0' + sqm_string;
              }
              _sign = ( SqmCalOffset < 0 ) ? '-' : ' ';
              sqm_string = _sign + sqm_string;
              temp_string = String( ( TempCalOffset < 0 )? -TempCalOffset : TempCalOffset, 1);  
              while ( temp_string.length() < 5) {
                temp_string = '0' + temp_string;
              }
              _sign = ( TempCalOffset < 0 ) ? '-' : ' ';
              temp_string = _sign + temp_string;
              oled[4]= (ReadEEAutoContras())? '1' : '0';
              Serial.print("g," + sqm_string  + "m," 
                             + temp_string + "C,TC:" 
                             + (( ReadEEAutoTempCal())? "Y," : "N,") 
                             + oled 
                             + ",DC:" );
              Serial.println(ReadEEcontras());                                  
                                                     
// Configuration commad                     
          }   else if ( command[0] == 'z' ) {
              response = command.substring(1,4);

           if ( response.equals("cal")) { 
              char _x = command[4];                       
              if (  _x == '1') {    // Calibration Light offest 1
                response = command.substring(5); 
                SqmCalOffset=response.toFloat();        
                WriteEESqmCalOffset(SqmCalOffset);          
                sqm_string = String( (SqmCalOffset <0 )? -SqmCalOffset : SqmCalOffset , 2);
                while ( sqm_string.length() < 5) {
                   sqm_string = '0' + sqm_string;
                }
                _sign = ( SqmCalOffset < 0 ) ? '-' : ' ';
                sqm_string = _sign + sqm_string;
                Serial.println("z,1,"+ sqm_string + 'm');
              } 
              
// Calibration Temperature
              else if  ( _x == '2') {  
                
                response = command.substring(5); 
                TempCalOffset=response.toFloat();          
                WriteEETempCalOffset(TempCalOffset); 
                temp_string = String( ( TempCalOffset < 0 )? -TempCalOffset : TempCalOffset, 1);
                while ( temp_string.length() < 5) {
                  temp_string = '0' + temp_string;
                }
                _sign = ( TempCalOffset < 0 ) ? '-' : ' ';
                temp_string = _sign + temp_string;
                Serial.println("z,2," + temp_string + 'C');
              } 

// Set display contras                                
               else if ( _x == '3') {           
                   response = command.substring(5);
                   WriteEEScontras( response.toInt());         
                   Serial.println("z,3," + command.substring(5) + 'x');                
               }
               
// Enable temperature callibration               
               else if ( _x == 'e') { 
                    WriteEEAutoTempCal(true);
                    Serial.println("zeaL");                        
               }

// Disable temperature callibration (note lower case "d")            
               else if ( _x == 'd') { 
                    WriteEEAutoTempCal(false);
                  //  sqm.resetTemperature();
                    Serial.println("zdaL");                        
               }

// Delete calibration (note upper case "D") - set default factory value see Setup.h              
               else if ( _x == 'D') {  
                  SqmCalOffset =  SQM_CAL_OFFSET ;   // set to default 
                  TempCalOffset = TEMP_CAL_OFFSET;   // set to default 
                  WriteEETempCalOffset(TempCalOffset); 
                  WriteEESqmCalOffset(SqmCalOffset); 
                  WriteEEScontras(DEFALUT_CONTRAS); 
                  Serial.println("zxdL");                        
               }
          }           
          
// Disable Oled Display          
        } else if (command.equals("A50")) {
          oled[3] = '0';
          OledDisp.setPowerSave(true);        
          Serial.println(oled);
// Enable Oled Display                    
        } else if (command.equals("A51")) {
          oled[3] = '1';
          OledDisp.setPowerSave(false); 
          Serial.println(oled);       
// Disable Autocontras - Dimmer                    
        } else if (command.equals("A5d")) {
          oled[4] = '0';
          WriteEEAutoContras(false);
          Serial.println(oled);
// Enable Autocontras - Dimmer                             
        } else if (command.equals("A5e")) {
          oled[4] = '1';
          WriteEEAutoContras(true);
          Serial.println(oled);
// Display status          
        } else if (command.equals("A5")) {
          oled[4]= (ReadEEAutoContras())? '1' : '0';
          Serial.println(oled);
        }
// View current information
        DisplSqm( mag, 0, int(temp+0.5), int(hum), int(pres / 100), '@');
        SqmCalOffset  = ReadEESqmCalOffset();    // SQM Calibration offset from EEPROM
        TempCalOffset = ReadEETempCalOffset();   // Temperature Calibration offset from EEPROM
        // sqm.setCalibrationOffset(SqmCalOffset);
       
    } // end of while ( Serial.available() )
  }  // end of if (digitalRead(ModePin)) 
} // end of loop()

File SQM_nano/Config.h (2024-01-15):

// Config.h 
// User specific configuration for SQM
// 
// Copyright (c) 2019 Roman Hujer   http://hujer.net
//
#ifndef CONFIG_H
#define CONFIG_H

#define SERIAL_BAUD 115200    //Serial port baud Default is 115200

// Select only one your display
#define SH1106_ON  // SH1106  1.3"  128x64 OLED display is default
#define SSD1306_OFF // SSD1306 0.96" 128x64 OLED display 

#define EXTENDET_INFO_ON  // Two extended Startup info screen
 
#define EXTENDET_PROTOCOL_OFF  // My Extender protocol for weather info (Disable when is project compilation Big)

#define DEFALUT_CONTRAS 0     // default Display contras


#define SQM_CAL_OFFSET  -1.0  // default SQM Calibration offset but priority is in EEPROM stored value
#define TEMP_CAL_OFFSET 0.0   // default Temperature Calibration offset but priority is in EEPROM stored value

#endif

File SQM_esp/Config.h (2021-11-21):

/*

 * Copyright (c) 2020 Roman Hujer 

*/

const char* host       = "my.cloud.iot";
String app             = "/app.bin";  //URI for HTTP GET  app
#define HTTP_PORT  80

const char* ssid       = "my_ssid";
const char* password   = "my_password";

const char* SensorID = "SQM-ESP01";
const char* sensor_key = "xxxxxxxxxxxxxxxxxx";  // For auth on web server

//select chip
#define ESP01_ON  // For ESP-01 is _ON for full ESP8266 is _OFF 
#define DEEP_SLEEP_OFF  //only ESP8266 for battery run  

//#define SERIAL_BAUD 74880  // 74880 default  pro ESP chip boot  (For some Linux need use 115200)   
#define SERIAL_BAUD 115200


#define EEPROM_OFF         // USE eeprom for store callibration values 
#define SQM_CAL_OFFSET  -2.50  // default SQM Calibration offset but priority is in EEPROM stored value
#define TEMP_CAL_OFFSET 0.0    // default Temperature Calibration offset but priority is in EEPROM stored value

#define SLEEP_SEC 300   // Interval

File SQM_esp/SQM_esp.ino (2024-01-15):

/*

   Copyright (c) 2020 Roman Hujer

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
*/

#define Product "SQM ESP"
#define Version "1.0"

#include <Wire.h>
#include <ESP8266WiFi.h>
#include <EEPROM.h>
#include <OneWire.h>
#include <DallasTemperature.h>
 

//
//#include "Config.h"
// My testing config
#include "myConfig.h"


#include "Setup.h"



#include <BMx280I2C.h>
BMx280I2C bme(BME_I2C_ADDRESS);



#include "SQM_TSL2591.h"


// Setup for SQM TSL2591
SQM_TSL2591 sqm = SQM_TSL2591(2591);

float SqmCalOffset =  SQM_CAL_OFFSET ;   // SQM Calibration offset from EEPROM
float TempCalOffset = TEMP_CAL_OFFSET;   // Temperature Calibration offset from EEPROM

// Setup a oneWire instance to communicate with any OneWire device
OneWire oneWire(ONE_WIRE_BUS);  
 
// Pass oneWire reference to DallasTemperature library
DallasTemperature sensors(&oneWire);

boolean InitError = false;
boolean Humidity  = true;

float temp = 0;
float temp2 = 0; 
float hum =  0;
float pres = 0;
float mas =  0;
float dmas = 0;
 
uint16_t counter = 0;
String BME_Msg;
String TSL_Msg;
String WiFi_Msg;

void setup()
{
  sensors.begin();
  
#ifdef ESP01_ON
  Wire.begin(0, 2); // I2C pin ESP01
#else
  Wire.begin();   // I2C pin ESP8266 
#endif
  Serial.begin(SERIAL_BAUD);
  Serial.setTimeout(1000);
  Serial.println();

  WiFi.mode(WIFI_STA);
  WiFi.begin(ssid, password);
retry:
  Serial.printf("Wait for WiFi.");
  for (uint8_t t = 30; t > 0; t--) {
    if ( WiFi.status() == WL_CONNECTED ) break;
    Serial.print(".");
    delay(500);
  }
  if (WiFi.status() != WL_CONNECTED) {
    Serial.printf("\nWIFI not connect. Now sleep retry next 60sec...");
#ifdef DEEP_SLEEP_ON
    ESP.deepSleep(60e6);
#else
    delay (60000);
    goto retry;
#endif
  }
  Serial.println("");
  Serial.println("WiFi connected");
  Serial.print("IP address: ");
  Serial.println(WiFi.localIP());

  if ( bme.begin()) {
    if (bme.isBME280()) {
      Humidity = true;
      BME_Msg  = "BME280  OK";
      bme.resetToDefaults();
      bme.writeOversamplingPressure(BMx280MI::OSRS_P_x16);
      bme.writeOversamplingTemperature(BMx280MI::OSRS_T_x16);
      bme.writeOversamplingHumidity(BMx280MI::OSRS_H_x16);
    } else {
      Humidity = false;
      BME_Msg =  "no Humidity";
    }
  } else {
    BME_Msg =  "BME Err";
    InitError = true;
  }
  Serial.println(BME_Msg);
  
// init SQM sensor
  void readSQM(void);
  if (sqm.begin()) {
    sqm.verbose = false;
    sqm.config.gain = TSL2591_GAIN_LOW;
    sqm.config.time = TSL2591_INTEGRATIONTIME_200MS;
    sqm.configSensor();
    sqm.showConfig();
    TSL_Msg = "TSL2591 OK";
  }
  else {
    TSL_Msg = "TSL2591 Err";
    InitError = true;
  } // end of if (sqm.begin())

  Serial.println(TSL_Msg);

#ifdef  EEPROM_ON
  SqmCalOffset = ReadEESqmCalOffset();     // SQM Calibration offset from EEPROM
  TempCalOffset = ReadEETempCalOffset();   // Temperature Calibration offset from EEPROM
#else 
  SqmCalOffset =  SQM_CAL_OFFSET;  
  TempCalOffset = TEMP_CAL_OFFSET; 
#endif

  sqm.setCalibrationOffset(SqmCalOffset);  // call offset
}

void loop()
{
  String response;
  String url;
  float battery = 0;
 
  sensors.requestTemperatures(); 
  temp2 = sensors.getTempCByIndex(0);
  ReadWeather();
  
  if (ReadEEAutoTempCal()) sqm.setTemperature( temp );  //temp call
  
  sqm.takeReading();  
  
  mas = sqm.mpsas;
  dmas = sqm.dmpsas;
  battery = int(analogRead(A0) / 1023.0 * 11 * 100 + 0.5) / 100.;
  Serial.println("");
  Serial.print("SQM: ");
  Serial.print(mas);
  Serial.print("+-");
  Serial.print(dmas);
  Serial.println("mas^2");
  Serial.print("Temp1: ");
  Serial.print(temp);
  Serial.println("°C");
  Serial.print("Temp2: ");
  Serial.print(temp2);
  Serial.println("°C");
  Serial.print("Humidity: ");
  Serial.print(hum );
  Serial.println("%");
  Serial.print("Pressure: ");
  Serial.print(pres/100);
  Serial.println(" hPa");
#ifndef ESP01_ON  
  Serial.print("Battery Voltage: ");
  Serial.println(battery);
#endif
    url = "?ID=";
    url += SensorID;
    url += "&KEY=";
    url += sensor_key;
    url += "&T=";
    url +=  temp2;
    url += "&B=";
    url +=  temp;
    url += "&H=";
    url += hum;
    url += "&P=";
    url += pres/100;
    url += "&S=";
    url += mas;
    url += "&D=";
    url += dmas;
#ifndef ESP01_ON     
    url += "&V=";
    url += battery;
#endif    
    send_cloud ( url  );

#ifdef DEEP_SLEEP_ON
/// WAKE_RF_DEFAULT, WAKE_RFCAL, WAKE_NO_RFCAL, WAKE_RF_DISABLED.
  Serial.println("WiFi disconnet");
  WiFi.disconnect();
  delay(100);
  Serial.println("Deep sleep.");
  ESP.deepSleep(SLEEP_SEC * 1000000);
#else
  delay( SLEEP_SEC * 1000); // cekej
#endif
}

void send_cloud ( String url)
{
  

  WiFiClient wifi_client;
  const int httpPort = HTTP_PORT;


  if (!wifi_client.connect(host, httpPort)) {
    Serial.println("connection failed");
    return;
  }

  // This will send the request to the server
  wifi_client.print(String("GET ") + app + url + " HTTP/1.1\r\n" +
                    "Host: " + host + "\r\n" +
                    "Connection: close\r\n\r\n");
  unsigned long timeout = millis();
  while (wifi_client.available() == 0) {
    if (millis() - timeout > 5000) {
      Serial.println("HTTP Timeout !");
      wifi_client.stop();
      return;
    }
  }

  // Read all the lines of the reply from server and print them to Serial
  while (wifi_client.available()) {
    String line = wifi_client.readStringUntil('\r');
   Serial.print(line);
  }
  Serial.println();
  Serial.println("closing connection");

}


void ReadWeather() {
  if ( bme.measure() ) {

    do {
      delay(100);
    } while (!bme.hasValue());
    pres = bme.getPressure();
    temp = bme.getTemperature();
    if ( Humidity) hum =  bme.getHumidity();
    else hum = 0;
    temp = temp + TempCalOffset;  //calll

  }
}

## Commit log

2019-09-30 Temperature calibration
2019-10-01 FreeCAD SQMBox
    [SQM PCB V1.0.dxf, SQMBoxB.stl, SQM_BOX.FCStd]
2019-10-02 Box update
    [SQMBoxB.stl, SQMBoxT.stl, SQM_BOX.FCStd]
2019-10-04 update 3d models
    [SQMBoxB.stl, SQMBoxB_fixed.obj, SQMBoxB_fixed.stl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]
2019-10-04 Add extended protokol
    [SQMFaceSSD1106.stl, SQMFaceSSD1106_fixed.obj, SQMFaceSSD1106_fixed.stl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]
2019-10-13 Mode Pin reverse for HW 1.1b
    [SQM.ino, Setup.h]
2019-10-13 Add PCB a update 3D models
    [SQMBoxB.stl, SQMBoxB_fixed.obj, SQMBoxB_fixed.stl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]
2019-10-13 Change directory strusture
    [SQM PCB V1.0.dxf, SQMBoxB_fixed.obj, SQMBoxB_fixed.stl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]
2019-10-13 Update doc
    [SQM PCB V1.0.dxf, SQMBoxB_fixed.obj, SQMBoxB_fixed.stl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]
2019-10-13 SSD1306 face
    [SQMFaceSSD1306_fixed.obj, SQMFaceSSD1306_fixed.stl, SQM_BOX.FCStd]
2019-10-13 Update PCB Gerber
2019-11-05 add thread cllass
2020-02-24 Add ESP-01 Box
    [ESP-01 SQM.dxf, ESP-01-SQM-box_fixed.obj, ESP-01-SQM-cap_fixed.obj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]
2020-02-25 Add SQM ESP8266 box
    [SQM ESP v2.dxf, SQM-ESP8266-box_fixed.obj, SQM-ESP8266-box_main.stl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]
2020-02-25 update ESP8266
    [SQM-ESP8266-usb.stl, SQM-ESP8266-usb_fixed.obj, SQM_BOX.FCStd]
2020-02-26 FIX esp8266 BOX
    [SQM-ESP-holder.stl, SQM-ESP-holder_fixed.obj, SQM-ESP8266-cover-main.stl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]
2020-02-28 Fix ESP8266 battery
2020-06-19 SQM pro
    [SQM ESP pro V2.5_2020-06-01_20-28-58.dxf, flexbatter.scad, flexbatterAAx3.stl]

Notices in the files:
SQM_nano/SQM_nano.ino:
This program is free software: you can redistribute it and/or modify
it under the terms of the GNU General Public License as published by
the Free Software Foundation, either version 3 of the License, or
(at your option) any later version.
